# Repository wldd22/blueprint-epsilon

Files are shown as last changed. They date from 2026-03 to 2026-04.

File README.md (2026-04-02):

# Epsilon
Columnar split keyboard with 5 columns, 4 rows, and thumb clusters. Made for [Hackclub's Blueprint](https://blueprint.hackclub.com/)

## Details
PCB made using KiCAD \
Case made using Fusion360 \
Firmware made using ZMK

## About
I've always wanted to use a split keyboard, and after making a macropad, I decided the next step was to make a bigger keyboard that could actually replace my regular one for at least some daily use.

## Images

### CAD
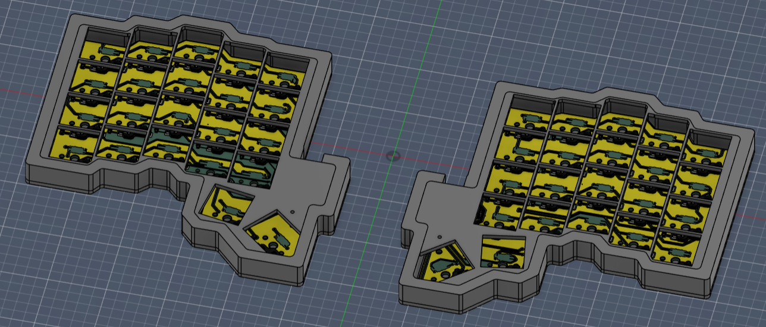
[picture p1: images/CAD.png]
CAD

### Schematic
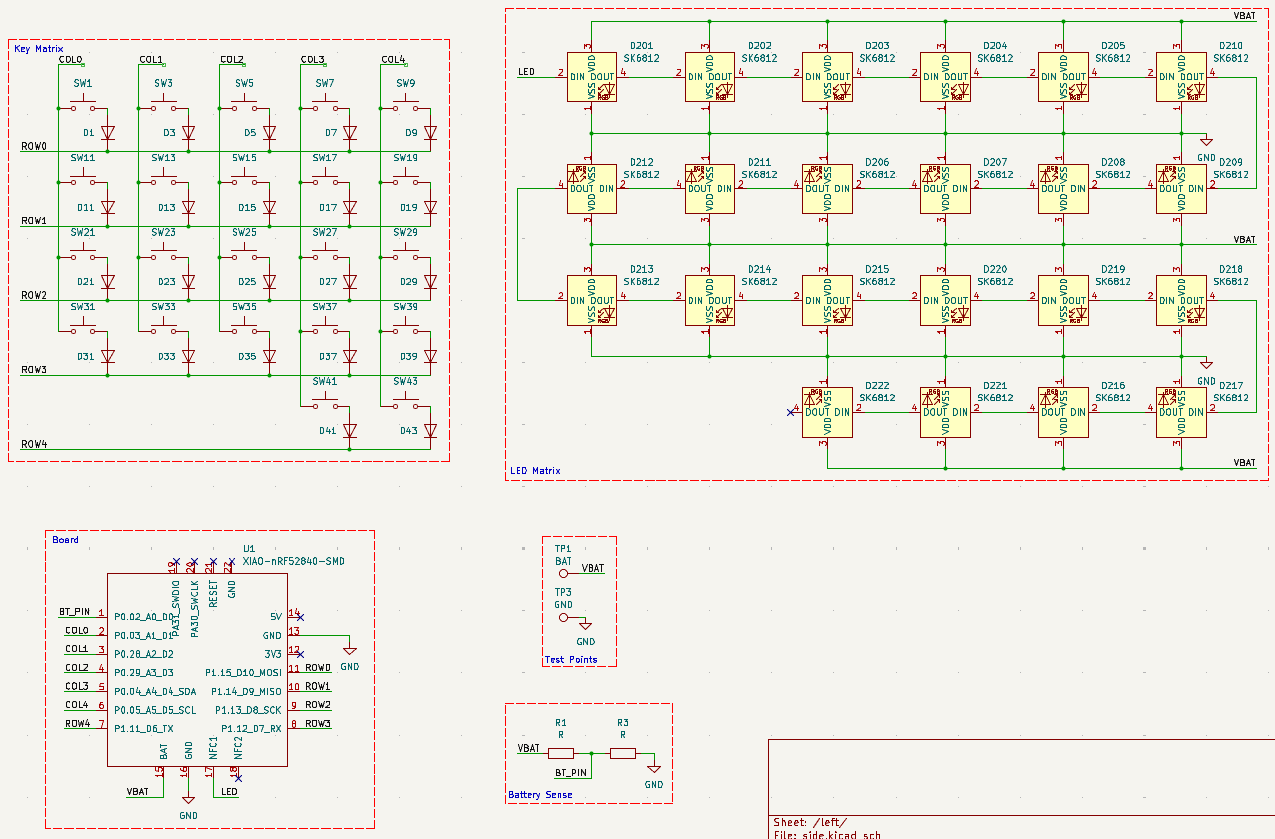
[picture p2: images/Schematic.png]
Schematic


### PCB
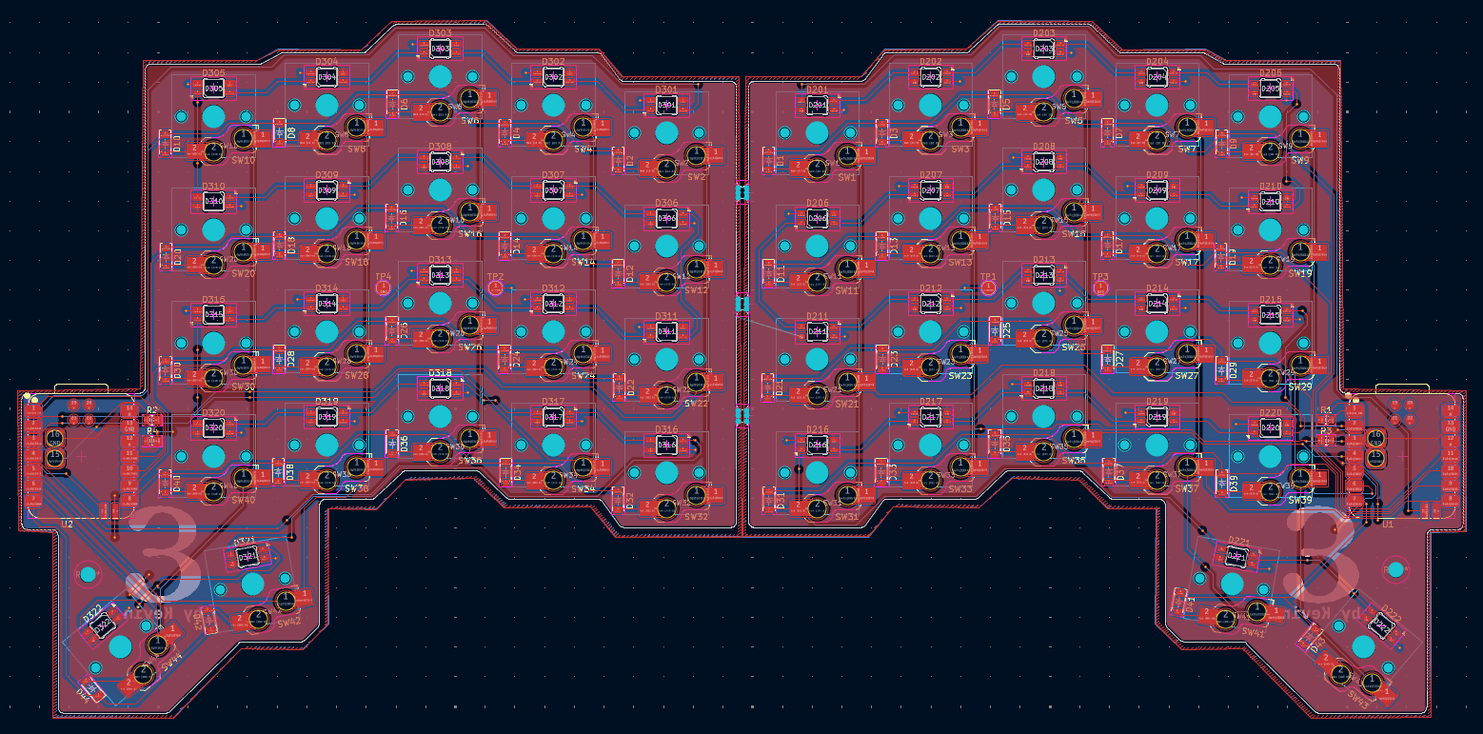
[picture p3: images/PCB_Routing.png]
PCB Routing

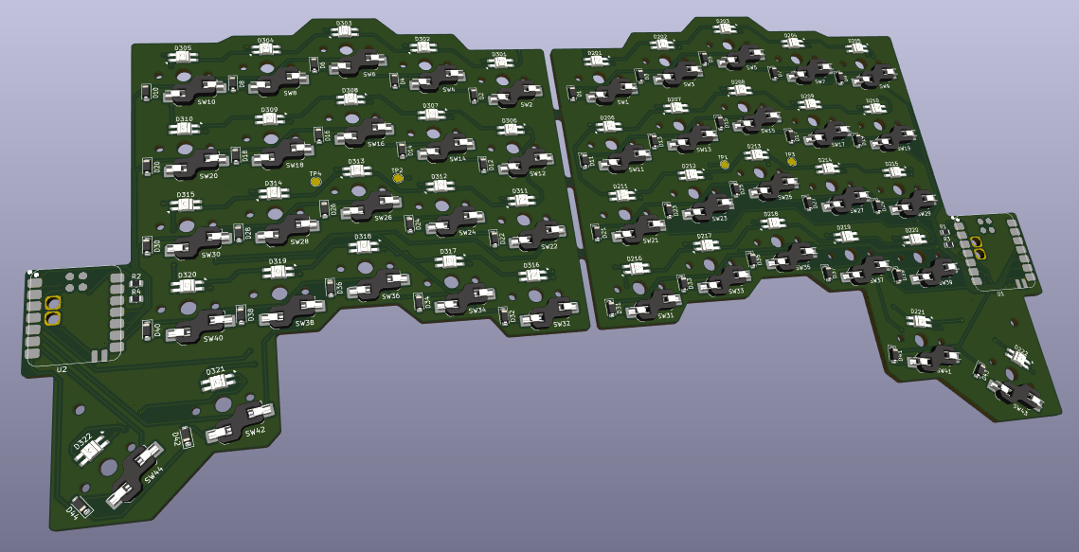
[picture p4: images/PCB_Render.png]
PCB Render


### Case
| Left Side | Right Side |
|-|-|
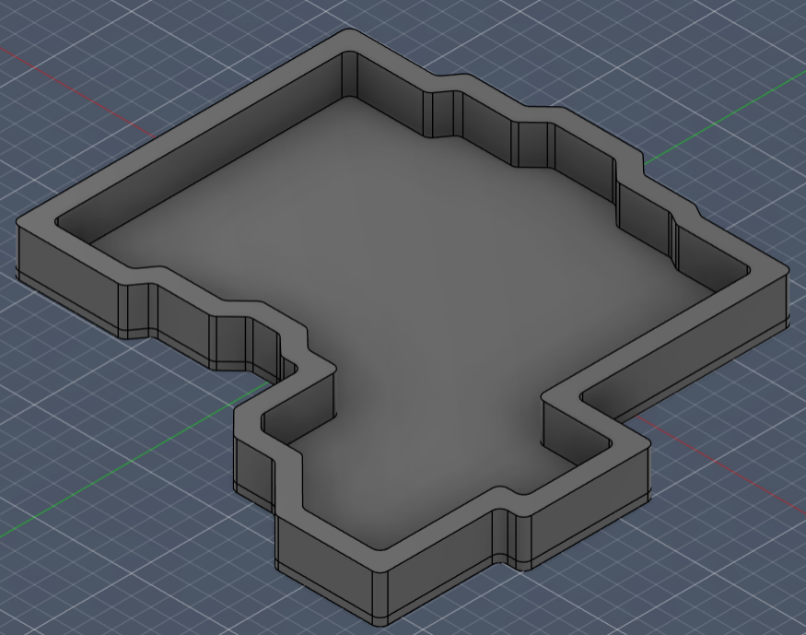
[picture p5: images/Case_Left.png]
Case Left
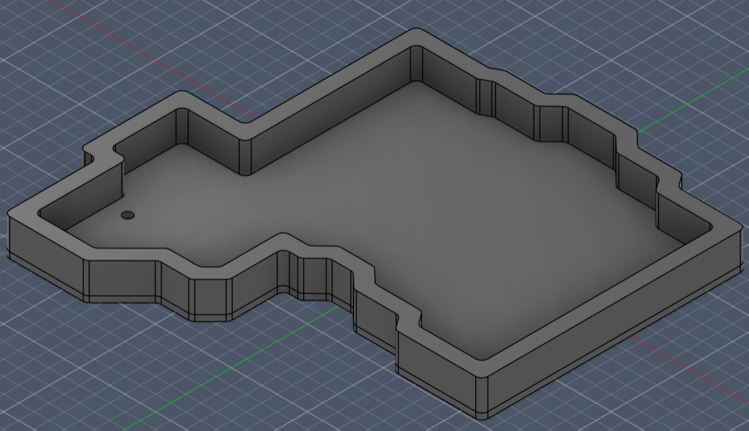
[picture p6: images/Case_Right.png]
Case Right
|  |  |

## BOM

| Item | Description | Quantity | Source | Cost | Amount |
| --- | --- | --- | --- | --- | --- |
| JLC PCB | Left and right sides in one piece | 1 | JLCPCB | $15.30 | $15.30 |
| JLC shipping | UPS Worldwide Express Saver | - | - | - | $15.67 |
| Case (shipping only) | Left and right sides separately | 2 | Printing Legion | - | ~$5 |
| Kalih Hotswap Sockets | Hotswap sockets for Choc V1 switches (x10) | 5 (44 + 6 extra) | [Chosfox](https://chosfox.com/products/kailh-choc-switch-1350-hot-swap-sockets) | $1.45 | $7.25 |
| Kailh Choc Low Profile Switches | Kalih Choc Brown Switches (Tactile) (x10) | 5 (44 + 6 extra) | [Chosfox](https://chosfox.com/products/kailh-chocs?variant=42514647646402) | $4.5 | $22.50 |
| Chosfox shipping | Standard Shipping China Post | - | - | - | $5.20 |
| CFX Choc Keycaps | Chocfox CFX Choc Blank Keycaps (Black) (x10) | 5 (44 + 6 extra) | [NeoMacro](https://typeractive.xyz/products/mbk-keycaps?variant=48512019562727) | ₹350 | ₹1750 (free shipping) |
| SK6812 MINI-E RGB | RGB LEDs (x50) | 1 (44 + 6 extra) | [Desertcart](https://www.desertcart.in/products/713547616-50pcs-sk6812-mini-e-rgb-similar-with-ws2812b-sk6812-3228) | ₹1219 | ₹1219 (free shipping) |
| Seeed Studio XIAO nRF52840 | Microcontroller | 2 | [ThinkRobotics](https://thinkrobotics.com/products/seeed-studio-xiao-nrf52840) | ₹1419.93 | ₹2839.86 (free shipping) |
| 1N4148 Diodes | 1N4148W SOD-123 Diodes | 44 | [Robu](https://robu.in/product/1n4148w-sod-123-1206-diodereel-of-3000/) | ₹0.57 (10+) | ₹25.08 |
| AC0805FR-072ML-YAGEO | 2MΩ Resistor | 2 | [Robu](https://robu.in/product/ac0805fr-072ml-yageo-res-thick-film-0805-2m-ohm-1-0-125w1-8w-%C2%B1100ppm-c-pad-smd-t-r-automotive-aec-q200/) | ₹0.64 | ₹1.28 |
| RT0805FRE071ML-YAGEO | 1MΩ Resistor | 2 | [Robu](https://robu.in/product/rt0805fre071ml-yageo-125mw-thin-film-resistor-%C2%B150ppm-%E2%84%83-%C2%B11-1m%CF%89-0805-chip-resistor-surface-mount-rohs/) | ₹1.38 | ₹2.76 |
| Battery Jack | Black | 2 | [Robu](https://robu.in/product/s2b-ph-klfsn-jst-1x2p-2p-ph-tin-2-25%E2%84%8385%E2%84%83-2a-1-2mm-brass-bend-insert-push-pullp2mm-wire-to-board-connector-rohs/) | ₹13 | ₹26 |
| LiPo Battery | WLY752530 3.7V 500mAh 1S | 2 | [Robu](https://robu.in/product/500mah-pcm-protected-micro-li-po-battery/) | ₹261 | ₹522 |
| Robu shipping | Standard Shipping | - | - | - | ₹49 |
| 40x1 Pin 2.54mm Pitch Male Berg Strip | 40pin header | 1 | [Robocraze](https://robocraze.com/products/40x1-pin-2-54mm-pitch-male-berg-strip) | ₹6 | ₹6 |
| Robocraze shipping | Standard | - | - | - | ₹49 |
| M2 Screws | Stainless steel, 8mm | 4 | [StacksKB](https://stackskb.com/store/m2-screw-8mm-stainless-steel/) | ₹3.10 | ₹12.40 |
| M2 Hex Nuts | Stainless steel | 4 | [StacksKB](https://stackskb.com/store/m2-hex-nut-stainless-steel/) | ₹5 | ₹20 |
| StacksKB shipping | Standard | - | - | - | ₹130 |
| **TOTAL** | | | | | **~$141** |

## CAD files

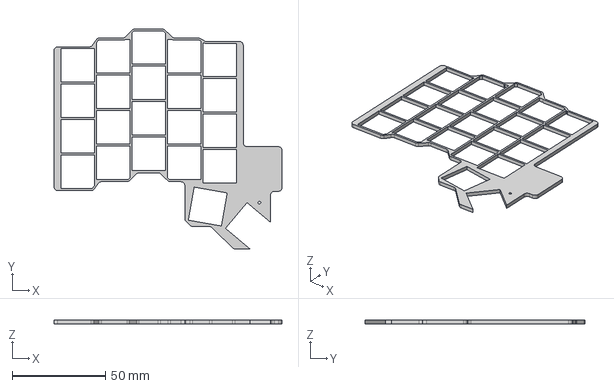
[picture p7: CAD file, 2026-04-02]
production/models/Case Left Top.step
122.2 x 117.8 x 2.00 mm

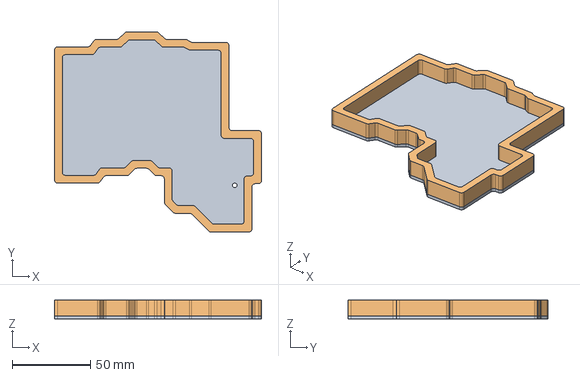
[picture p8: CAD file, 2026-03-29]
production/models/Case Left.step
132.2 x 127.8 x 12.0 mm

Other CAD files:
production/models/Case Right Top.step
production/models/Case Right.step

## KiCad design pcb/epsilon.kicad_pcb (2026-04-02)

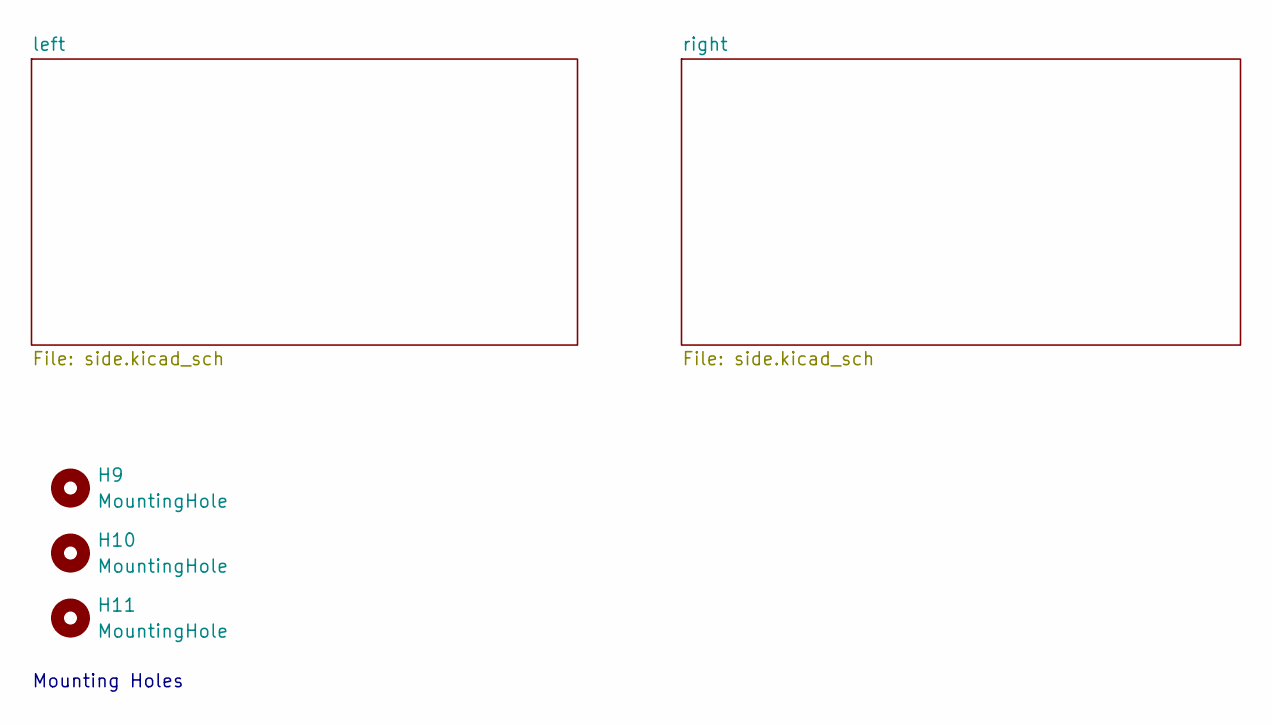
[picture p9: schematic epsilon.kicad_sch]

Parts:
H9, H10, H11: MountingHole; MouseBite-Slot_2.0x2.0mm_outset_D0.5mm_P0.85mm_3h

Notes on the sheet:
Mounting Holes

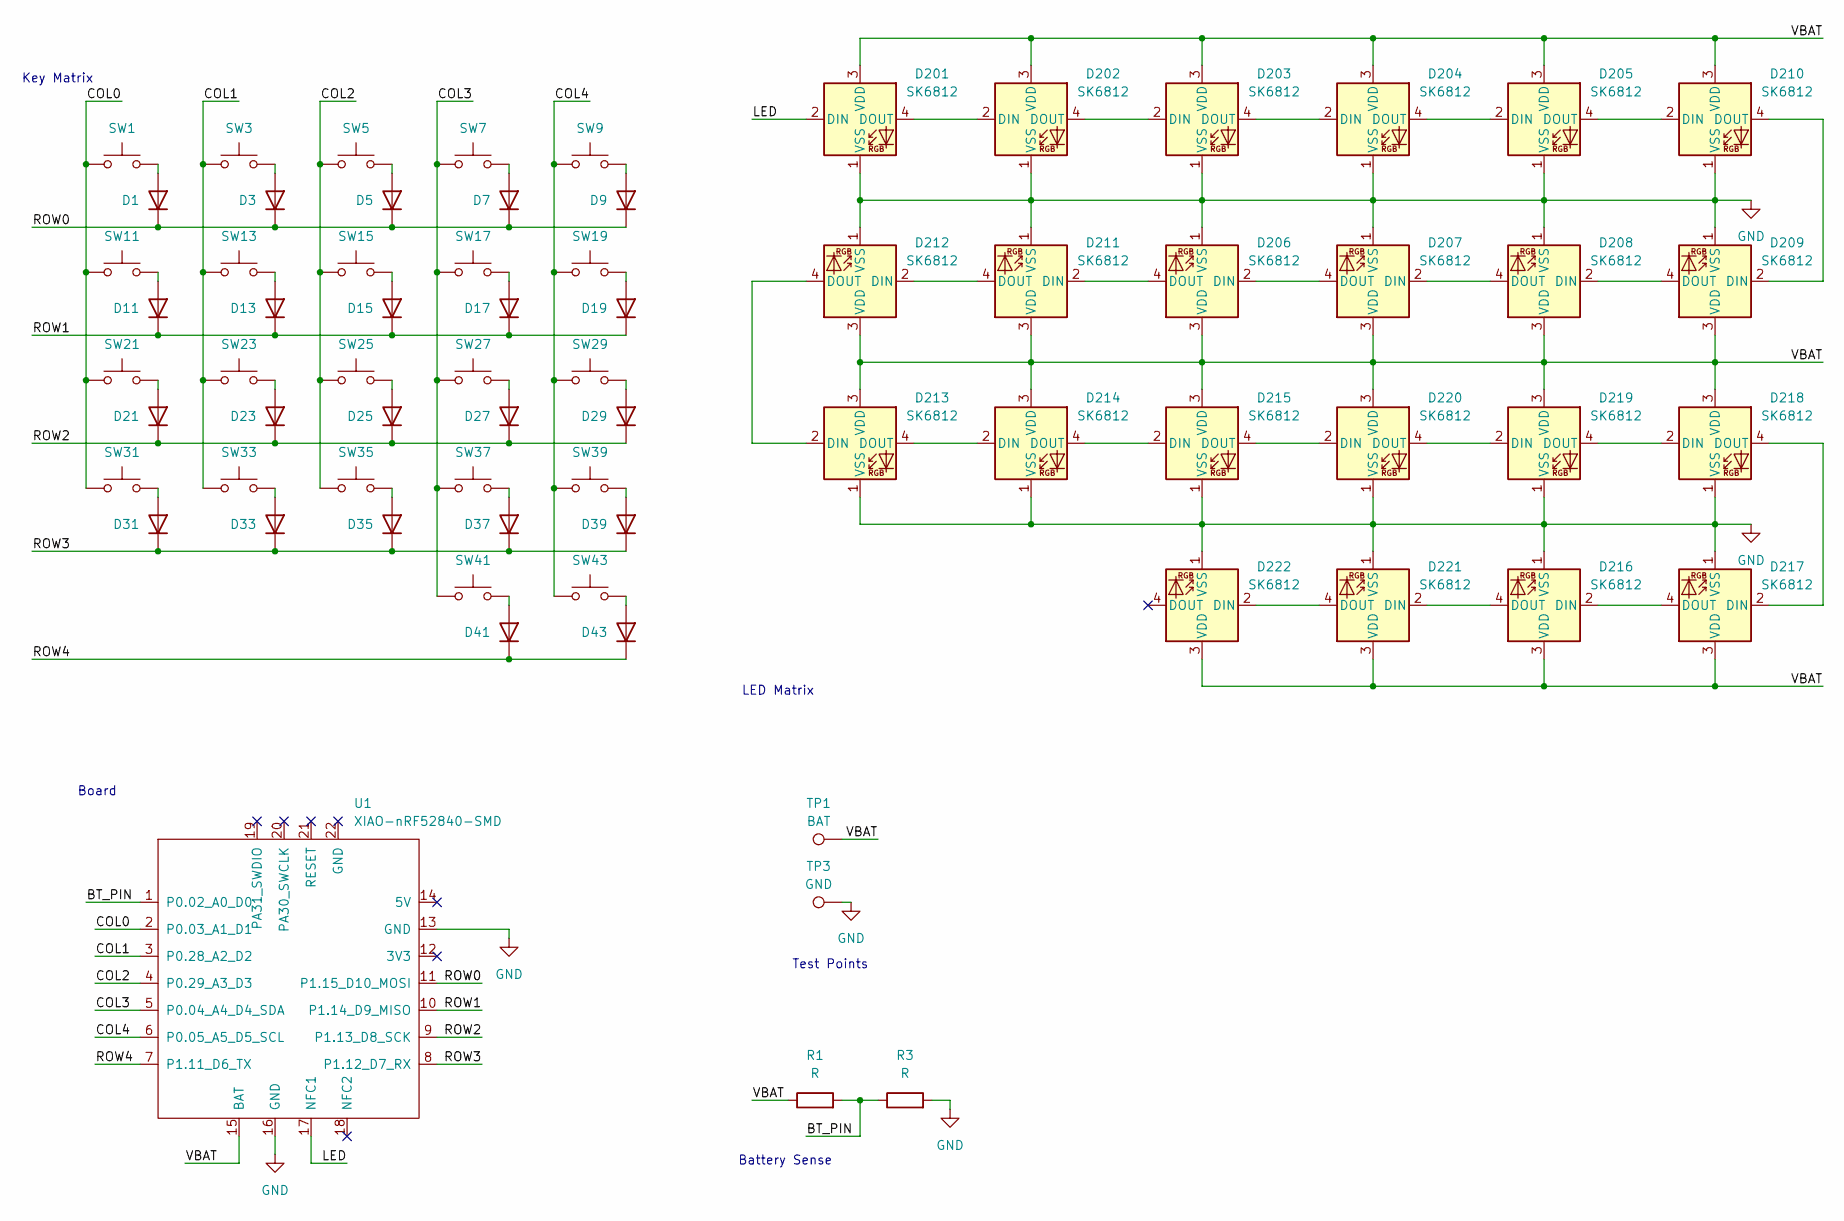
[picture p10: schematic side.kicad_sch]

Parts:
D1, D3, D5, D7, D9, D11, D13, D15, D17, D19, D21, D23, D25, D27, D29, D31, D33, D35, D37, D39, D41, D43: D; D_SOD-123
D201, D202, D203, D204, D205, D206, D207, D208, D209, D210, D211, D212, D213, D214, D215, D216, D217, D218, D219, D220, D221, D222: SK6812; LED_choc_6028R
R1, R3: R; R_0805_2012Metric
SW1, SW3, SW5, SW7, SW9, SW11, SW13, SW15, SW17, SW19, SW21, SW23, SW25, SW27, SW29, SW31, SW33, SW35, SW37, SW39, SW41, SW43: SW_Push; SW_choc_v1_HS_CPG135001S30_1u
TP1: BAT; TestPoint_Pad_D2.0mm
TP3: GND; TestPoint_Pad_D2.0mm
U1: XIAO-nRF52840-SMD; modified-XIAO-nRF52840-SMD

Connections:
/left/BT_PIN: R1.2, R3.1, U1.1 (P0.02_A0_D0)
/left/COL0: SW1.1, SW11.1, SW21.1, SW31.1, U1.2 (P0.03_A1_D1)
/left/COL1: SW3.1, SW13.1, SW23.1, SW33.1, U1.3 (P0.28_A2_D2)
/left/COL2: SW5.1, SW15.1, SW25.1, SW35.1, U1.4 (P0.29_A3_D3)
/left/COL3: SW7.1, SW17.1, SW27.1, SW37.1, SW41.1, U1.5 (P0.04_A4_D4_SDA)
/left/COL4: SW9.1, SW19.1, SW29.1, SW39.1, SW43.1, U1.6 (P0.05_A5_D5_SCL)
/left/LED: D201.2 (DIN), U1.17 (NFC1)
/left/ROW0: D1.1 (K), D3.1 (K), D5.1 (K), D7.1 (K), D9.1 (K), U1.11 (P1.15_D10_MOSI)
/left/ROW1: D11.1 (K), D13.1 (K), D15.1 (K), D17.1 (K), D19.1 (K), U1.10 (P1.14_D9_MISO)
/left/ROW2: D21.1 (K), D23.1 (K), D25.1 (K), D27.1 (K), D29.1 (K), U1.9 (P1.13_D8_SCK)
/left/ROW3: D31.1 (K), D33.1 (K), D35.1 (K), D37.1 (K), D39.1 (K), U1.8 (P1.12_D7_RX)
/left/ROW4: D41.1 (K), D43.1 (K), U1.7 (P1.11_D6_TX)
/left/VBAT: D201.3 (VDD), D202.3 (VDD), D203.3 (VDD), D204.3 (VDD), D205.3 (VDD), D206.3 (VDD), D207.3 (VDD), D208.3 (VDD), D209.3 (VDD), D210.3 (VDD), D211.3 (VDD), D212.3 (VDD), D213.3 (VDD), D214.3 (VDD), D215.3 (VDD), D216.3 (VDD), D217.3 (VDD), D218.3 (VDD), D219.3 (VDD), D220.3 (VDD), D221.3 (VDD), D222.3 (VDD), R1.1, TP1.1, U1.15 (BAT)
GND: D201.1 (VSS), D202.1 (VSS), D203.1 (VSS), D204.1 (VSS), D205.1 (VSS), D206.1 (VSS), D207.1 (VSS), D208.1 (VSS), D209.1 (VSS), D210.1 (VSS), D211.1 (VSS), D212.1 (VSS), D213.1 (VSS), D214.1 (VSS), D215.1 (VSS), D216.1 (VSS), D217.1 (VSS), D218.1 (VSS), D219.1 (VSS), D220.1 (VSS), D221.1 (VSS), D222.1 (VSS), R3.2, TP3.1, U1.13 (GND), U1.16 (GND); also elsewhere on the board
unnamed: D1.2 (A), SW1.2
unnamed: D3.2 (A), SW3.2
unnamed: D5.2 (A), SW5.2
unnamed: D7.2 (A), SW7.2
unnamed: D9.2 (A), SW9.2
unnamed: D11.2 (A), SW11.2
unnamed: D13.2 (A), SW13.2
unnamed: D15.2 (A), SW15.2
unnamed: D17.2 (A), SW17.2
unnamed: D19.2 (A), SW19.2
unnamed: D21.2 (A), SW21.2
unnamed: D23.2 (A), SW23.2
unnamed: D25.2 (A), SW25.2
unnamed: D27.2 (A), SW27.2
unnamed: D29.2 (A), SW29.2
unnamed: D31.2 (A), SW31.2
unnamed: D33.2 (A), SW33.2
unnamed: D35.2 (A), SW35.2
unnamed: D37.2 (A), SW37.2
unnamed: D39.2 (A), SW39.2
unnamed: D41.2 (A), SW41.2
unnamed: D43.2 (A), SW43.2
unnamed: D201.4 (DOUT), D202.2 (DIN)
unnamed: D202.4 (DOUT), D203.2 (DIN)
unnamed: D203.4 (DOUT), D204.2 (DIN)
unnamed: D204.4 (DOUT), D205.2 (DIN)
unnamed: D205.4 (DOUT), D210.2 (DIN)
unnamed: D206.2 (DIN), D207.4 (DOUT)
unnamed: D206.4 (DOUT), D211.2 (DIN)
unnamed: D207.2 (DIN), D208.4 (DOUT)
unnamed: D208.2 (DIN), D209.4 (DOUT)
unnamed: D209.2 (DIN), D210.4 (DOUT)
unnamed: D211.4 (DOUT), D212.2 (DIN)
unnamed: D212.4 (DOUT), D213.2 (DIN)
unnamed: D213.4 (DOUT), D214.2 (DIN)
unnamed: D214.4 (DOUT), D215.2 (DIN)
unnamed: D215.4 (DOUT), D220.2 (DIN)
unnamed: D216.2 (DIN), D217.4 (DOUT)
unnamed: D216.4 (DOUT), D221.2 (DIN)
unnamed: D217.2 (DIN), D218.4 (DOUT)
unnamed: D218.2 (DIN), D219.4 (DOUT)
unnamed: D219.2 (DIN), D220.4 (DOUT)
unnamed: D221.4 (DOUT), D222.2 (DIN)

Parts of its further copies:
D2, D4, D6, D8, D10, D12, D14, D16, D18, D20, D22, D24, D26, D28, D30, D32, D34, D36, D38, D40, D42, D44: D; D_SOD-123
D301, D302, D303, D304, D305, D306, D307, D308, D309, D310, D311, D312, D313, D314, D315, D316, D317, D318, D319, D320, D321, D322: SK6812; LED_choc_6028R
R2, R4: R; R_0805_2012Metric
SW2, SW4, SW6, SW8, SW10, SW12, SW14, SW16, SW18, SW20, SW22, SW24, SW26, SW28, SW30, SW32, SW34, SW36, SW38, SW40, SW42, SW44: SW_Push; SW_choc_v1_HS_CPG135001S30_1u
TP2: BAT; TestPoint_Pad_D2.0mm
TP4: GND; TestPoint_Pad_D2.0mm
U2: XIAO-nRF52840-SMD; modified-XIAO-nRF52840-SMD

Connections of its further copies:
/right/BT_PIN: R2.2, R4.1, U2.1 (P0.02_A0_D0)
/right/COL0: SW2.1, SW12.1, SW22.1, SW32.1, U2.2 (P0.03_A1_D1)
/right/COL1: SW4.1, SW14.1, SW24.1, SW34.1, U2.3 (P0.28_A2_D2)
/right/COL2: SW6.1, SW16.1, SW26.1, SW36.1, U2.4 (P0.29_A3_D3)
/right/COL3: SW8.1, SW18.1, SW28.1, SW38.1, SW42.1, U2.5 (P0.04_A4_D4_SDA)
/right/COL4: SW10.1, SW20.1, SW30.1, SW40.1, SW44.1, U2.6 (P0.05_A5_D5_SCL)
/right/LED: D301.2 (DIN), U2.17 (NFC1)
/right/ROW0: D2.1 (K), D4.1 (K), D6.1 (K), D8.1 (K), D10.1 (K), U2.11 (P1.15_D10_MOSI)
/right/ROW1: D12.1 (K), D14.1 (K), D16.1 (K), D18.1 (K), D20.1 (K), U2.10 (P1.14_D9_MISO)
/right/ROW2: D22.1 (K), D24.1 (K), D26.1 (K), D28.1 (K), D30.1 (K), U2.9 (P1.13_D8_SCK)
/right/ROW3: D32.1 (K), D34.1 (K), D36.1 (K), D38.1 (K), D40.1 (K), U2.8 (P1.12_D7_RX)
/right/ROW4: D42.1 (K), D44.1 (K), U2.7 (P1.11_D6_TX)
/right/VBAT: D301.3 (VDD), D302.3 (VDD), D303.3 (VDD), D304.3 (VDD), D305.3 (VDD), D306.3 (VDD), D307.3 (VDD), D308.3 (VDD), D309.3 (VDD), D310.3 (VDD), D311.3 (VDD), D312.3 (VDD), D313.3 (VDD), D314.3 (VDD), D315.3 (VDD), D316.3 (VDD), D317.3 (VDD), D318.3 (VDD), D319.3 (VDD), D320.3 (VDD), D321.3 (VDD), D322.3 (VDD), R2.1, TP2.1, U2.15 (BAT)
GND: D301.1 (VSS), D302.1 (VSS), D303.1 (VSS), D304.1 (VSS), D305.1 (VSS), D306.1 (VSS), D307.1 (VSS), D308.1 (VSS), D309.1 (VSS), D310.1 (VSS), D311.1 (VSS), D312.1 (VSS), D313.1 (VSS), D314.1 (VSS), D315.1 (VSS), D316.1 (VSS), D317.1 (VSS), D318.1 (VSS), D319.1 (VSS), D320.1 (VSS), D321.1 (VSS), D322.1 (VSS), R4.2, TP4.1, U2.13 (GND), U2.16 (GND); also elsewhere on the board
unnamed: D2.2 (A), SW2.2
unnamed: D4.2 (A), SW4.2
unnamed: D6.2 (A), SW6.2
unnamed: D8.2 (A), SW8.2
unnamed: D10.2 (A), SW10.2
unnamed: D12.2 (A), SW12.2
unnamed: D14.2 (A), SW14.2
unnamed: D16.2 (A), SW16.2
unnamed: D18.2 (A), SW18.2
unnamed: D20.2 (A), SW20.2
unnamed: D22.2 (A), SW22.2
unnamed: D24.2 (A), SW24.2
unnamed: D26.2 (A), SW26.2
unnamed: D28.2 (A), SW28.2
unnamed: D30.2 (A), SW30.2
unnamed: D32.2 (A), SW32.2
unnamed: D34.2 (A), SW34.2
unnamed: D36.2 (A), SW36.2
unnamed: D38.2 (A), SW38.2
unnamed: D40.2 (A), SW40.2
unnamed: D42.2 (A), SW42.2
unnamed: D44.2 (A), SW44.2
unnamed: D301.4 (DOUT), D302.2 (DIN)
unnamed: D302.4 (DOUT), D303.2 (DIN)
unnamed: D303.4 (DOUT), D304.2 (DIN)
unnamed: D304.4 (DOUT), D305.2 (DIN)
unnamed: D305.4 (DOUT), D310.2 (DIN)
unnamed: D306.2 (DIN), D307.4 (DOUT)
unnamed: D306.4 (DOUT), D311.2 (DIN)
unnamed: D307.2 (DIN), D308.4 (DOUT)
unnamed: D308.2 (DIN), D309.4 (DOUT)
unnamed: D309.2 (DIN), D310.4 (DOUT)
unnamed: D311.4 (DOUT), D312.2 (DIN)
unnamed: D312.4 (DOUT), D313.2 (DIN)
unnamed: D313.4 (DOUT), D314.2 (DIN)
unnamed: D314.4 (DOUT), D315.2 (DIN)
unnamed: D315.4 (DOUT), D320.2 (DIN)
unnamed: D316.2 (DIN), D317.4 (DOUT)
unnamed: D316.4 (DOUT), D321.2 (DIN)
unnamed: D317.2 (DIN), D318.4 (DOUT)
unnamed: D318.2 (DIN), D319.4 (DOUT)
unnamed: D319.2 (DIN), D320.4 (DOUT)
unnamed: D321.4 (DOUT), D322.2 (DIN)

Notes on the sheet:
Battery Sense
Test Points
Board
LED Matrix
Key Matrix

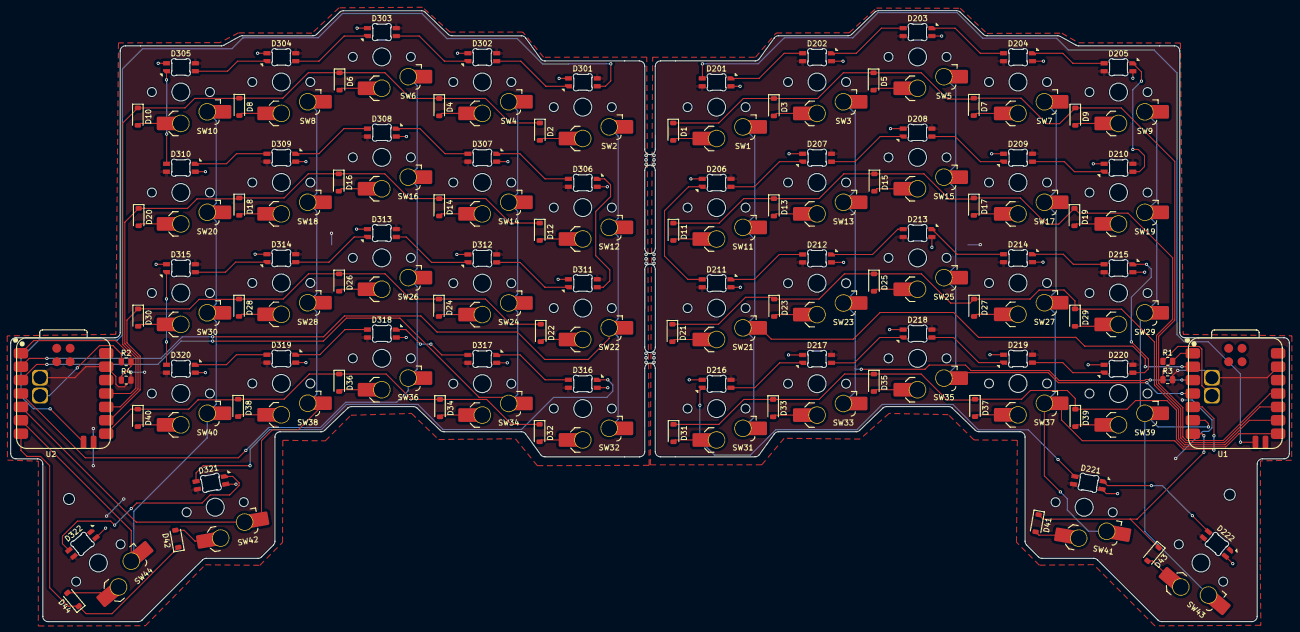
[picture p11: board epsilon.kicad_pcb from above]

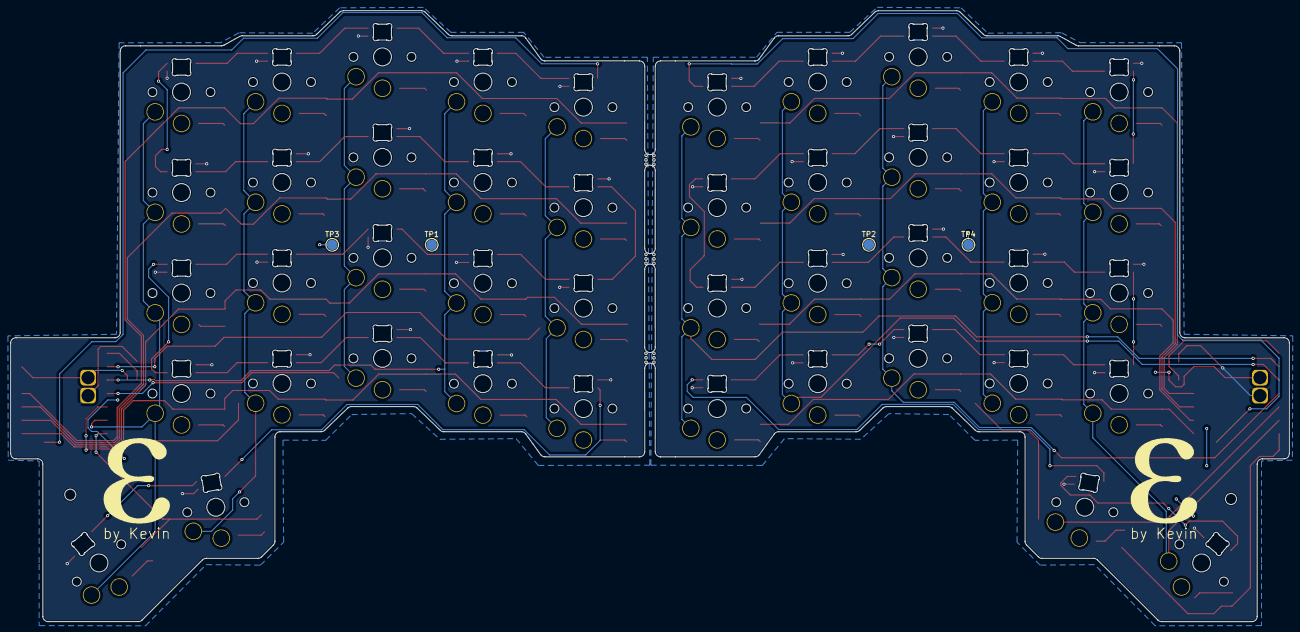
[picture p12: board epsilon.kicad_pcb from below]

Board: 2 copper layers, 242.4 x 115.8 mm, 145 parts (4 on the bottom side), 113 nets.

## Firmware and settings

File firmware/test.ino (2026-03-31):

#include <Adafruit_NeoPixel.h>

// =======================
// MATRIX CONFIG
// =======================
#define NUM_ROWS 5
#define NUM_COLS 5

// Column pins (outputs)
uint8_t colPins[NUM_COLS] = {2, 3, 4, 5, 6};

// Row pins (inputs)
uint8_t rowPins[NUM_ROWS] = {11, 10, 9, 8, 7};

// Thumb row only uses last 2 columns
bool validKey[NUM_ROWS][NUM_COLS] = {
  {1,1,1,1,1},
  {1,1,1,1,1},
  {1,1,1,1,1},
  {1,1,1,1,1},
  {0,0,0,1,1} // row 4 (thumb row)
};

// =======================
// LED CONFIG
// =======================
#define LED_PIN PIN_NFC1
#define NUM_LEDS 22

Adafruit_NeoPixel leds(NUM_LEDS, LED_PIN, NEO_GRB + NEO_KHZ800);

// =======================
// STATE TRACKING
// =======================
bool keyState[NUM_ROWS][NUM_COLS];
bool lastKeyState[NUM_ROWS][NUM_COLS];

unsigned long lastDebounceTime[NUM_ROWS][NUM_COLS];
#define DEBOUNCE_DELAY 10 // ms

// =======================
// LED INDEX MAPPING
// =======================
// Maps matrix position → LED index
int keyToLEDIndex[NUM_ROWS][NUM_COLS];
int ledCounter = 0;

// =======================
// SETUP
// =======================
void setup() {
  Serial.begin(115200);
  delay(1000);

  // Setup columns (outputs)
  for (int c = 0; c < NUM_COLS; c++) {
    pinMode(colPins[c], OUTPUT);
    digitalWrite(colPins[c], HIGH);
  }

  // Setup rows (inputs with pullups)
  for (int r = 0; r < NUM_ROWS; r++) {
    pinMode(rowPins[r], INPUT_PULLUP);
  }

  // Build LED mapping
  for (int r = 0; r < NUM_ROWS; r++) {
    for (int c = 0; c < NUM_COLS; c++) {
      if (validKey[r][c]) {
        keyToLEDIndex[r][c] = ledCounter++;
      } else {
        keyToLEDIndex[r][c] = -1;
      }
    }
  }

  leds.begin();
  leds.clear();
  leds.show();

  startupAnimation();
}

// =======================
// STARTUP ANIMATION
// =======================
void startupAnimation() {
  for (int i = 0; i < NUM_LEDS; i++) {
    leds.clear();
    leds.setPixelColor(i, leds.Color(0, 50, 0)); // green
    leds.show();
    delay(50);
  }

  leds.clear();
  leds.show();
}

// =======================
// MAIN LOOP
// =======================
void loop() {
  scanMatrix();
}

// =======================
// MATRIX SCAN
// =======================
void scanMatrix() {
  for (int c = 0; c < NUM_COLS; c++) {

    // Activate column (LOW)
    digitalWrite(colPins[c], LOW);

    for (int r = 0; r < NUM_ROWS; r++) {

      if (!validKey[r][c]) continue;

      bool reading = (digitalRead(rowPins[r]) == LOW);

      if (reading != lastKeyState[r][c]) {
        lastDebounceTime[r][c] = millis();
      }

      if ((millis() - lastDebounceTime[r][c]) > DEBOUNCE_DELAY) {

        if (reading != keyState[r][c]) {
          keyState[r][c] = reading;

          if (reading) {
            onKeyPress(r, c);
          } else {
            onKeyRelease(r, c);
          }
        }
      }

      lastKeyState[r][c] = reading;
    }

    // Deactivate column
    digitalWrite(colPins[c], HIGH);
  }
}

// =======================
// EVENT HANDLERS
// =======================
void onKeyPress(int r, int c) {
  Serial.print("PRESS  R");
  Serial.print(r);
  Serial.print(" C");
  Serial.println(c);

  int ledIndex = keyToLEDIndex[r][c];
  if (ledIndex >= 0) {
    leds.setPixelColor(ledIndex, leds.Color(50, 50, 50)); // white
    leds.show();
  }
}

void onKeyRelease(int r, int c) {
  Serial.print("RELEASE R");
  Serial.print(r);
  Serial.print(" C");
  Serial.println(c);

  int ledIndex = keyToLEDIndex[r][c];
  if (ledIndex >= 0) {
    leds.setPixelColor(ledIndex, 0);
    leds.show();
  }
}

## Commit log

2026-02-09 Finished schematic, started layout
    [epsilon.kicad_pcb, epsilon.kicad_sch, side.kicad_sch]
2026-02-09 Added LEDs to schematic, updated layout
    [epsilon.kicad_pcb, side.kicad_sch]
2026-02-13 Finish layout (mostly), route components
    [epsilon.kicad_pcb, side.kicad_sch]
2026-02-14 Add left side and mousebites
    [epsilon.kicad_pcb]
2026-02-14 Add logo and tag
    [epsilon.kicad_pcb]
2026-02-15 Add User.1, User.2, and User.3 layers
    [epsilon.kicad_pcb]
2026-02-28 Update User layers
    [epsilon.kicad_pcb]
2026-03-29 Add mounting holes in PCB
    [epsilon.kicad_pcb]
2026-03-29 Add gerbers
    [epsilon-B_Cu.gbl, epsilon-B_Mask.gbs, epsilon-B_Paste.gbp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]
2026-03-29 Add steps
    [Case Left.step, Case Right.step]
2026-03-31 Add BOM
2026-03-31 Modify PCB
2026-04-02 Optimise BOM and add shipping costs
2026-04-02 Optimise BOM further
2026-04-02 Add PCB models
    [epsilon.kicad_pcb]
2026-04-02 Add case tops
    [Case Left Top.step, Case Right Top.step]
2026-04-02 Add CAD image
2026-04-02 Add CAD files
